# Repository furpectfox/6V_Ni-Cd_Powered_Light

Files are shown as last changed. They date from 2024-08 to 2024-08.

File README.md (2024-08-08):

# 6 Ni-Cd Cells Charger

This circuit is designed to charge 5 Ni-Cd cells, in series, via a 5V USB source.

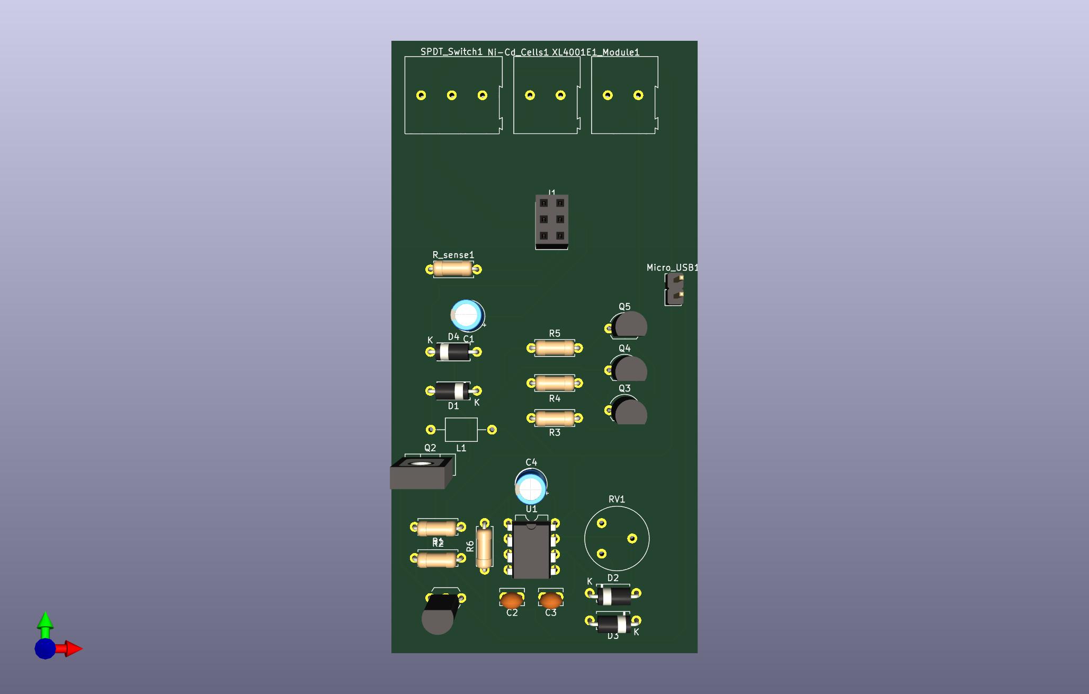
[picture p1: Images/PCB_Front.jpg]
PCB_Front

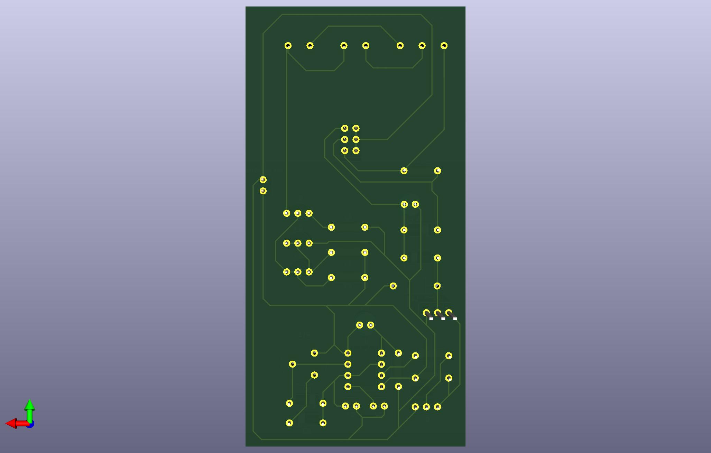
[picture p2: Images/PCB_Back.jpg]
PCB_Back


## Overview
The cells are trickle-charged at a constant current of 60mA (0.1C). The current is generated by a simple transistor constant current circuit. Care must be taken so that the voltage across the transistor is minimal so that power consumption is low and the transistor won't heat up too much. Charging will typically be completed after around 16 hours. However, because the charging current is low, it prevents the gas-venting effect in Ni-Cd batteries, allowing the cells to be left on the charger indefinitely.

Challenge: Since each cell has a nominal voltage of 1.2V, the total voltage of 5 cells in series is 6V, which is higher than the 5V USB source. As the cells are charged up, the voltage of each cell rises closer to 1.4V, thus increasing the total voltage further. In addition, other components of the charging circuit increases the total voltage by around 2V (voltage across current-set resistor, voltage across transistor, voltage across protection diode).

Solution: Boost the 5V USB to at 9V or more with a simple boost converter circuit. 'Simple' because this circuit does not have any feedback (at all!) to ensure the voltage stays constant if the load changes. I figured this would be fine because the current consumed by the load (the charging circuit) would be relatively constant. After some testing, I found this to be the case.

## Features
- There is a 1ohm resistor in series with the Ni-Cd battery pack, which allows the user to 'measure' the charging current by measuring the voltage across the resistor, where I(charging) = V(R-1ohm) / 1ohm

## Note
- The provided schematic includes the boost converter and constant-current charging circuit for the cells. It also provides screw-terminal connections for a XL4001E1 constant-currrent LED driver module. 

## Future Improvements
- Even though the circuit works fine at the moment, some type of feedback control should be added to the boost converter to make sure that the output voltage stays constant, for safety and efficiency concerns.

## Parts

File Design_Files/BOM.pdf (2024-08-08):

Column1 Column2 | Column3 | Column4 Column5
Id | Designator | Footprint | Quantity | Designation
1 | U1 | DIP-8_W7.62mm | 1 | NE555P
2 | Micro_USB1 | PinHeader_1x02_P2.54mm_Vertical | 1 | Conn_01x02_Pin
3 | D3,D2,D1 | D_A-405_P7.62mm_Horizontal | 3 | 1N5817
4 | R4,R3,R1 | R_Axial_DIN0207_L6.3mm_D2.5mm_P7.62mm_Horizontal | 3 | 1K
5 | Q3,Q4,Q5 | TO-92L_Inline_Wide | 3 | Q_NPN_EBC
6 | C2 | C_Disc_D3.8mm_W2.6mm_P2.50mm | 1 | 0.01u
7 | SPDT_Switch1 | TerminalBlock_Altech_AK300-3_P5.00mm | 1 | Screw_Terminal_01x03
8 | Q1 | TO-92L_Inline_Wide | 1 | 2N2222A
9 | XL4001E1_Module1,Ni-Cd_Cells1 TerminalBlock_Altech_AK300-2_P5.00mm | 2 | Screw_Terminal_01x02
10 | C3 | C_Disc_D3.8mm_W2.6mm_P2.50mm | 1 | 1n
11 | RV1 | Potentiometer_Piher_PT-10-V05_Vertical | 1 | 10K
12 | L1 | L_Axial_L5.0mm_D3.6mm_P10.00mm_Horizontal_Murata_BL01RN1A2A2 1 | 100u
13 | C4,C1 | CP_Radial_D5.0mm_P2.50mm | 2 | 100u
14 | D4 | D_A-405_P7.62mm_Horizontal | 1 | 1N4001
15 | R6 | R_Axial_DIN0207_L6.3mm_D2.5mm_P7.62mm_Horizontal | 1 | 0
16 | R5 | R_Axial_DIN0207_L6.3mm_D2.5mm_P7.62mm_Horizontal | 1 | 10
17 | J1 | PinSocket_2x03_P2.54mm_Vertical | 1 | Conn_02x03_Odd_Even
18 | R_sense1 | R_Axial_DIN0207_L6.3mm_D2.5mm_P7.62mm_Horizontal | 1 | 1
19 | R2 | R_Axial_DIN0207_L6.3mm_D2.5mm_P7.62mm_Horizontal | 1 | 470
20 | Q2 | TO-126-3_Vertical | 1 | IRF840

Column6 Column7 Column8
Supplier and ref

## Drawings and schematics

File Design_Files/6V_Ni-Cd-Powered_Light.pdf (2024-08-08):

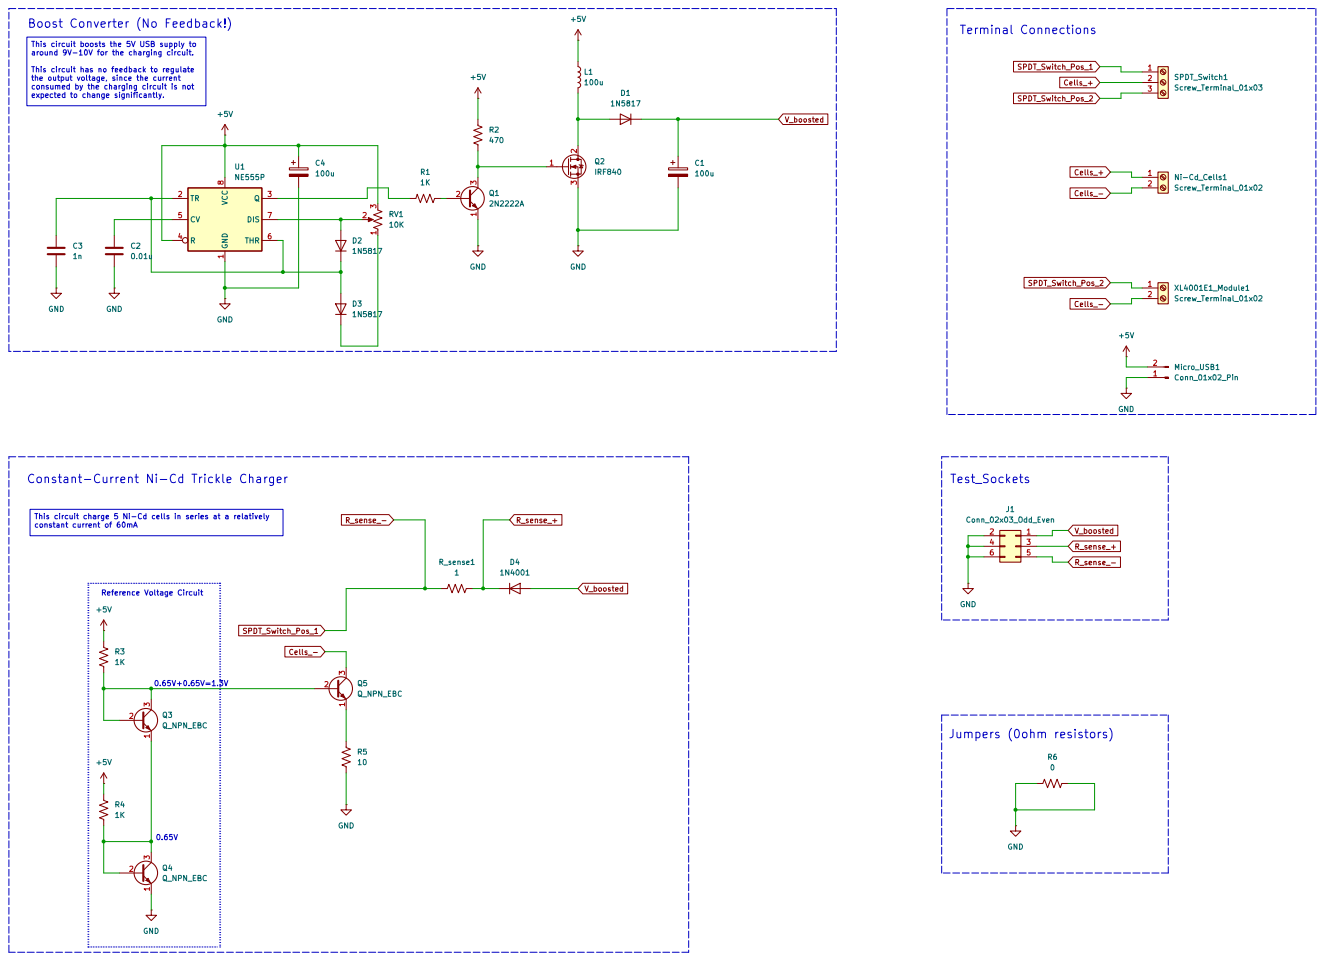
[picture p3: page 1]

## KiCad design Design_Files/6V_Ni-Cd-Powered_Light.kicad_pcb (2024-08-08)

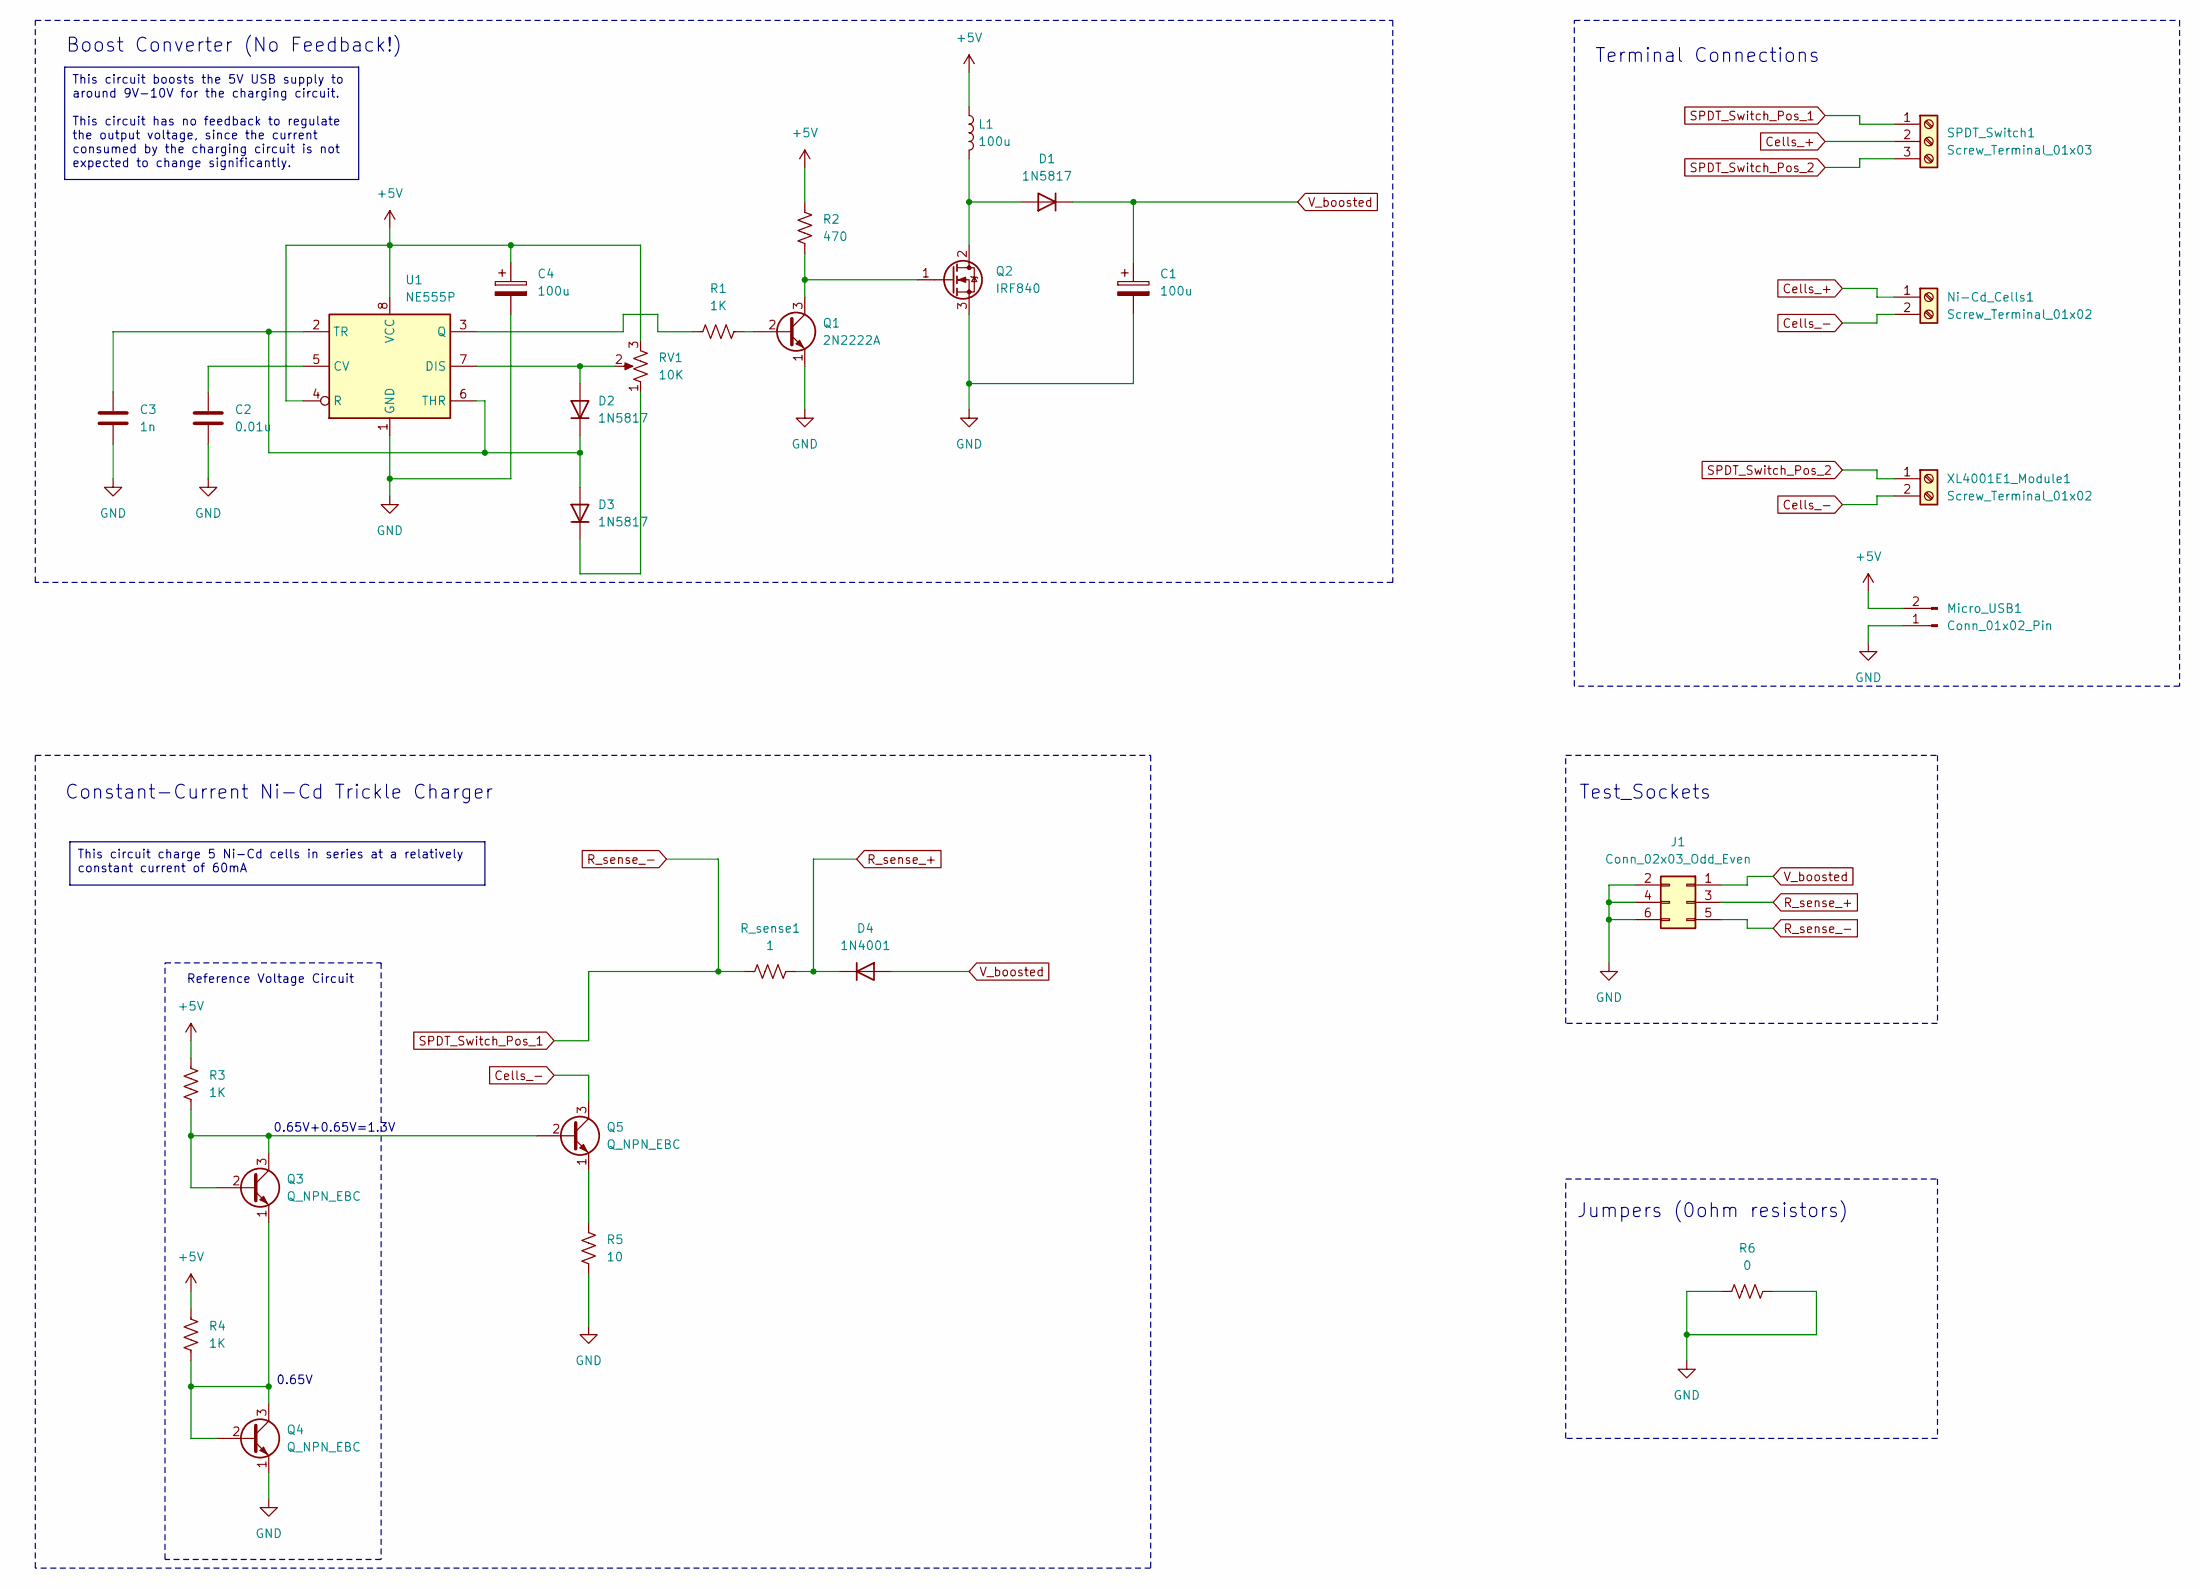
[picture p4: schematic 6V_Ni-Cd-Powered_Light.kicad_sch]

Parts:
C1, C4: 100u; CP_Radial_D5.0mm_P2.50mm
C2: 0.01u; C_Disc_D3.8mm_W2.6mm_P2.50mm
C3: 1n; C_Disc_D3.8mm_W2.6mm_P2.50mm
D1, D2, D3: 1N5817; D_A-405_P7.62mm_Horizontal
D4: 1N4001; D_A-405_P7.62mm_Horizontal
J1: Conn_02x03_Odd_Even; PinSocket_2x03_P2.54mm_Vertical
L1: 100u; L_Axial_L5.0mm_D3.6mm_P10.00mm_Horizontal_Murata_BL01RN1A2A2
Micro_USB1: Conn_01x02_Pin; PinHeader_1x02_P2.54mm_Vertical
Ni-Cd_Cells1: Screw_Terminal_01x02; TerminalBlock_Altech_AK300-2_P5.00mm
Q1: 2N2222A; TO-92L_Inline_Wide
Q2: IRF840; TO-126-3_Vertical
Q3, Q4, Q5: Q_NPN_EBC; TO-92L_Inline_Wide
R1, R3, R4: 1K; R_Axial_DIN0207_L6.3mm_D2.5mm_P7.62mm_Horizontal
R2: 470; R_Axial_DIN0207_L6.3mm_D2.5mm_P7.62mm_Horizontal
R5: 10; R_Axial_DIN0207_L6.3mm_D2.5mm_P7.62mm_Horizontal
R6: 0; R_Axial_DIN0207_L6.3mm_D2.5mm_P7.62mm_Horizontal
RV1: 10K; Potentiometer_Piher_PT-10-V05_Vertical
R_sense1: 1; R_Axial_DIN0207_L6.3mm_D2.5mm_P7.62mm_Horizontal
SPDT_Switch1: Screw_Terminal_01x03; TerminalBlock_Altech_AK300-3_P5.00mm
U1: NE555P; DIP-8_W7.62mm
XL4001E1_Module1: Screw_Terminal_01x02; TerminalBlock_Altech_AK300-2_P5.00mm

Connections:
+5V: C4.1, L1.1, Micro_USB1.2, R2.2, R3.2, R4.2, RV1.3, U1.4 (R), U1.8 (VCC)
Cells_+: Ni-Cd_Cells1.1, SPDT_Switch1.2
Cells_-: Ni-Cd_Cells1.2, Q5.3 (C), XL4001E1_Module1.2
GND: C1.2, C2.2, C3.2, C4.2, J1.2, J1.4, J1.6, Micro_USB1.1, Q1.1 (E), Q2.3 (S), Q4.1 (E), R5.1, R6.1, R6.2, U1.1 (GND)
unnamed: D1.2 (A), L1.2, Q2.2 (D)
unnamed: D2.2 (A), RV1.2, U1.7 (DIS)
unnamed: C3.1, D2.1 (K), D3.2 (A), U1.2 (TR), U1.6 (THR)
unnamed: D3.1 (K), RV1.1
unnamed: Q1.2 (B), R1.2
unnamed: Q1.3 (C), Q2.1 (G), R2.1
unnamed: Q3.2 (B), Q3.3 (C), Q5.2 (B), R3.1
unnamed: Q3.1 (E), Q4.2 (B), Q4.3 (C), R4.1
unnamed: Q5.1 (E), R5.2
unnamed: C2.1, U1.5 (CV)
unnamed: R1.1, U1.3 (Q)
R_sense_+: D4.1 (K), J1.3, R_sense1.1
R_sense_-: J1.5, R_sense1.2, SPDT_Switch1.1
SPDT_Switch_Pos_2: SPDT_Switch1.3, XL4001E1_Module1.1
V_boosted: C1.1, D1.1 (K), D4.2 (A), J1.1

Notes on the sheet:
This circuit boosts the 5V USB supply to around 9V-10V for the charging circuit. This circuit has no feedback to regulate the output voltage, since the current consumed by the charging circuit is not expected to change significantly.
This circuit charge 5 Ni-Cd cells in series at a relatively constant current of 60mA
Boost Converter (No Feedback!)
0.65V
Terminal Connections
Test_Sockets
0.65V+0.65V=1.3V
Reference Voltage Circuit
Constant-Current Ni-Cd Trickle Charger
Jumpers (0ohm resistors)

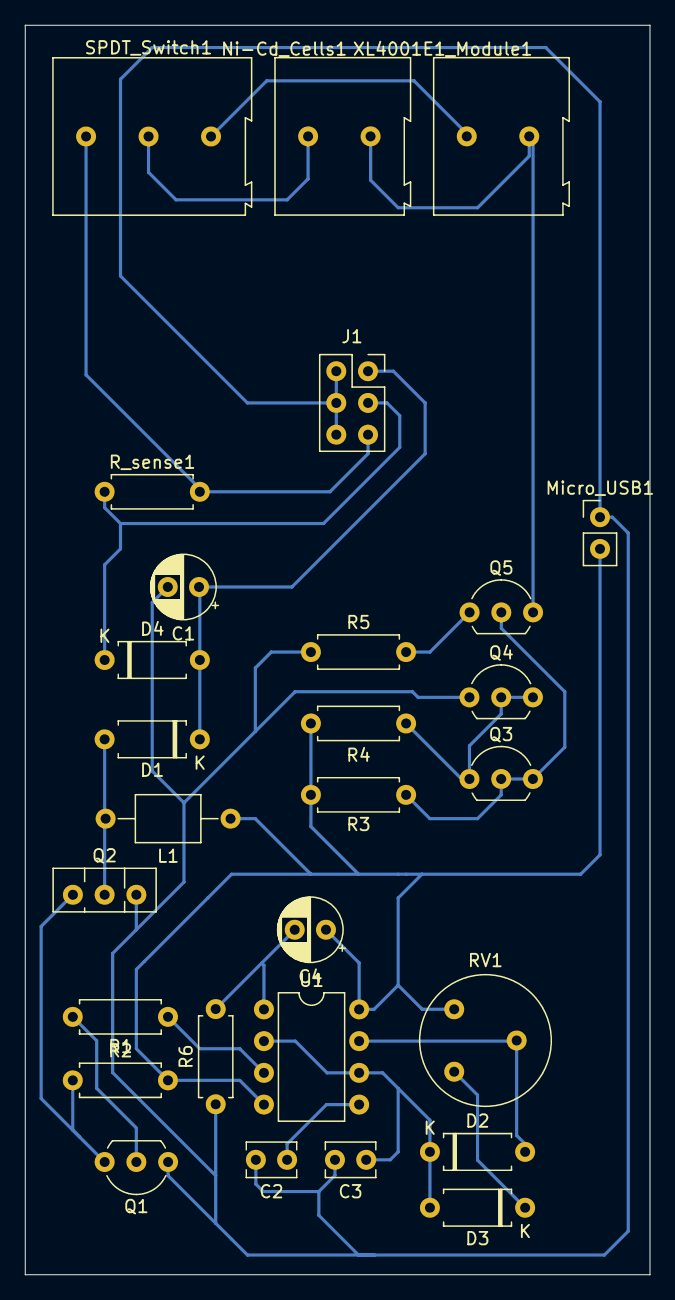
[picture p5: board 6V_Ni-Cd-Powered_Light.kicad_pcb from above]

Board: 2 copper layers, 50.0 x 100.0 mm, 28 parts (0 on the bottom side), 19 nets.
